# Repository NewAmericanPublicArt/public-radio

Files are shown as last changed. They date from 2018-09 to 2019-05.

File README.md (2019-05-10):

# Arduino Uno [Branch]
*NOTE* that this branch contains code for building the radio with an `Arduino Uno` using a slightly different board design. With this board we kept all of the components at 5V so we avoid all of the level-shifters that were required with the micro:bit. The board contains the following components:

 * Arduino Uno
 * [Adafruit Si4713]

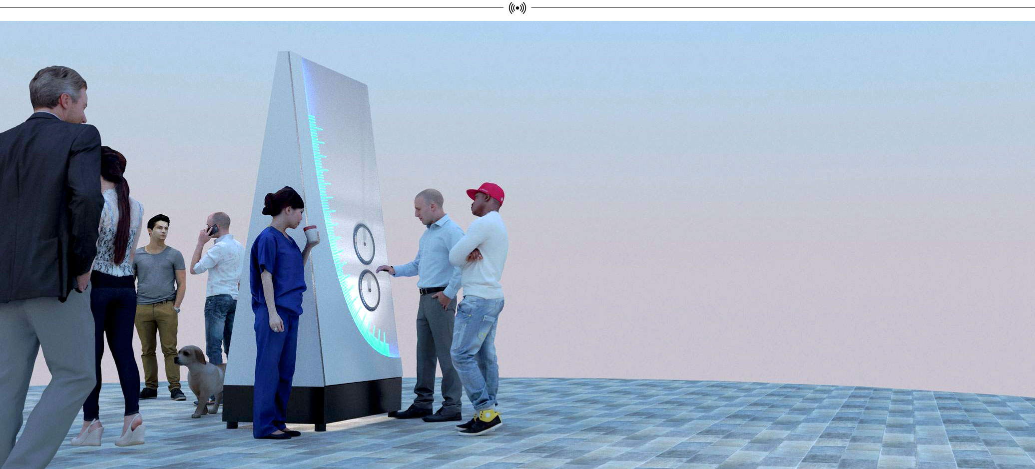
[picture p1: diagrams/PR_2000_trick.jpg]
title banner Public Radio Banner

# Public Radio
*Public Radio* was designed and fabricated by [New American Public Art](http://www.newamericanpublicart.com/) with electronic design &amp; programming by [Andrew Ringler](https://andrewringler.com/). This repository holds the Arduino code and electronic design documentation that drives the *Public Radio*.  

*Public Radio* is a large outdoor radio that continually plays over-the-air FM radio. It has two dials, one for changing station and one for changing volume. It provides visual feedback with LEDs of the currently selected station as well the current volume level. Additionally it provides audio feedback of the current station and volume by actually playing the selected FM station.

## New Developer Setup
The micro:bit was programmed using the Arduino IDE. If you need to make changes and re-upload the code first power off the radio, disconnect the USB cable from the micro:bit then pull the micro:bit out from the Dragontail connector.

In order to load the program onto a micro:bit you will need to:

 * Install the [Arduino IDE](https://www.arduino.cc/en/Main/Software) software
 * Follow the instructions at Adafruit's [Use Microbit with the Arduino IDE | Add NRF5x Board Support](https://learn.adafruit.com/use-micro-bit-with-arduino/install-board-and-blink#add-nrf5x-board-support-2-7) to add the NRF5x Board Support to your Arduino IDE. 
 * Download the entire repository: [as a zip here](https://github.com/NewAmericanPublicArt/public-radio/archive/master.zip)
 * From Arduino menu `Sketch > Include Library > Manage Libraries…` install the `Adafruit Dotstar` library (tested with v1.0.4) 

Once you have the NRF5x board installed, hook your micro:bit up to your computer via a USB cable. Then double-click the `PublicRadio/PublicRadio.ino` file to load the program in Arduino. Then update the following from Arduino menus `Tools > Board > BBC micro:bit`, `Tools > Softdevice > S110` and `Tools > Port > …BBC micro:bit…`

Then `Sketch > Upload`.

Put the micro:bit back into the Dragontail connector with the LED grid facing up. Power back on the radio.

## Design
*Public Radio* is a large 8x4 foot structure with an acrylic front panel. Two large dials (for channel tuning and volume changing) are mounted flush on the front panel. A curved string of LEDs are mounted on the interior left of the front panel which shine through to the outside providing visual feedback of the currently selected station. Tick marks and station labels (created by CNC cutting the front panel interior) line up with the LEDs. On the front bottom right a small string of LEDs provide visual feedback for the current volume level. Electronics (in waterproof boxes) as well as waterproof speakers are contained within the radio interior. The entire radio is controlled by a single BBC micro:bit.

A Fusion 360 model of the radio structure and components can be downloaded [here](https://a360.co/2QIU2CJ).

### Dials
The dials are attached to axles on the radio interior and on each axle is mounted a single black plexiglass disc with slits laser cut into an outer and an inner ring. The inner ring of slits is 1/2 slit-width out of phase with the outer ring. Two [Vernier VPG-BTD](https://www.vernier.com/products/sensors/vpg-btd/) photogates are mounted per encoder wheel such that one photogate measures the the outer ring of slits and the other photogate measures the inner ring of slits. This combination of using two photogates to measure the inner and outer rings of phase-shifted slits creates an optical incremental directional encoder whose readings we can interpret as a 2-bit Gray code pattern thus resolving the current speed of the axle and the direction the axle is rotating (clockwise versus counterclockwise). For more information on the concept of rotary encoders see [Rotary encoder](https://en.wikipedia.org/wiki/Rotary_encoder) on Wikipedia as well as Jeff Cook's University of Michigan [EECS 461](http://web.eecs.umich.edu/~jfr/embeddedctrls/lectures.html) Embedded Control Systems [Position and Velocity Lecture Notes](http://web.eecs.umich.edu/~jfr/embeddedctrls/files/Lecture3.pdf) (the lecture notes PDF is also available in our resources directory).

Each of the [Vernier VPG-BTD](https://www.vernier.com/products/sensors/vpg-btd/) Photogates is connected to a [Vernier BTA-ELV Analog Protoboard Adapter](https://www.vernier.com/products/accessories/protoboard-adapters/bta-elv/) which is a small breadboard compatible breakout board. We power the board with `5V` then measure pin `DIO0` which is `HIGH` when the photogate is blocked otherwise `LOW`. Since this is a `5V` board we first level-shift the `DIO0` signal down to `3.3V` with a `74AHCT125` level shifter then measure with a GPIO pin on the micro:bit.

We measure the speed and direction of each of the dials. If the station dial is turning clockwise the station increases, if the dial is turning counterclockwise the station decreases. The dials have no hard stops, so upon reaching the maximum station `107.9` while turning clockwise, we restart at the minimum station `86.5`, then continue to increase stations.

The volume dial also has no hard stops, but unlike the station dial, volume does not wrap-around from maximum volume to minimum volume since this would have created a jarring acoustic experience. Instead, we use a different technique we are calling `avocado volume`. Typically, while turning the volume dial clockwise the volume will increase until it reaches the maximum volume, then it will start decreasing, until it reaches the minimum volume, then it will start increasing again. So, if you continuously spin the dial clockwise, the volume of the radio will smoothly ramp up and down forever. Spinning the dials counterclockwise has the same behavior.

### Radio
The actual FM radio is driven by a digital `Si4703` FM tuner board. The micro:bit, on power-on, initializes the FM tuner board to a default station and volume. As the user changes station and volume, using the dials, these internal variables are updated and any changes are sent via `I²C` to the tuner board. The board tunes to the correct FM station and has a small pre-amp and 3.5mm audio jack. We hook a standard stereo audio cable to the board and then connect that to a standard audio amplifier which drives a set of waterproof consumer “deck” speakers.

The `Si4703` board we purchased (and most `Si4703` boards) did not have a separate FM antenna jack, instead the board pulls the signal from the shield of the audio cable. This is a less-than-ideal situation for FM reception. Madis Kaal [lists various options](http://www.nomad.ee/micros/silicon_radio/index.shtml) for dealing with this (also saved to the resources directory as *Si4703_MadisKaal_Antenna.pdf*). I decided to create a “breakout cable” that separates audio from the antenna.

#### Antenna | Audio Breakout Cable
The breakout cable is a stereo 3.5mm audio jack on one end (which attaches to the FM board) and the other end splits into a 3.5mm audio jack and a F-type RF connector (coax). The 3.5mm jack on the Si4703 board connects to a 3-part audio cable the 3 parts being [Tip, Ring and Shield/Sleeve aka TRS](https://en.wikipedia.org/wiki/Phone_connector_(audio)) which correspond to audio left, audio right and [antenna feed line](https://en.wikipedia.org/wiki/Feed_line). In the breakout cable the feedline is connected to the center conductor of the [F connector](https://en.wikipedia.org/wiki/F_connector) and the shield of the F connector is connected to a new ground line running to the board. On the audio side of the breakout cable the tip and ring are connected to the tip and ring again (IE left audio and right audio are as expected) and a new ground line is run to the shield of the audio cable (thus disconnecting the antenna feed line from the audio cable).

I connected the F connector to a standard dipole FM antenna via 75Ω coaxial cable. The audio cable is connected to a standard stereo audio amplifier and outdoor waterproof speakers.

### LEDs
384 `APA-102` LEDs curve along the left side of the front panel providing visual feedback of the current station. A small strip of 37 LEDs is on the bottom right side of the front panel providing feedback of current volume level. For wiring simplicity, all the LEDs are actually wired as a single continuously addressed strip of 421 LEDs with a small 6-inch jumper in between the station and volume LEDs so that to the volume LEDs could be physically and visually separated.

We chose APA-102 LEDs (over say WS2812B aka Adafruit Neopixels) since the APA-102s are a 4-wire spec with a dedicated clock line. Which essentially means they have very loose timing requirements because if you are interrupted by for example an interrupt you can just continue on after the interrupt with the correct clock signal. We actually read the photogates using interrupts so we don't miss any readings and can have very responsive dials. This would not have been possible with WS2812Bs. 

Again, like the Vernier photogates, the APA-102s are a 5V component so we used the 74AHCT125 level shifter to shift our 3.3V output from the micro:bit to the 5V level the APA-102s want. Although many 5V LEDs will sort-of tolerate a 3.3V input it is more robust to supply them with the 5V signal they expect.

### Breadboard Diagram:
Microbit controlling FM Receiver and APA102 LED light string:
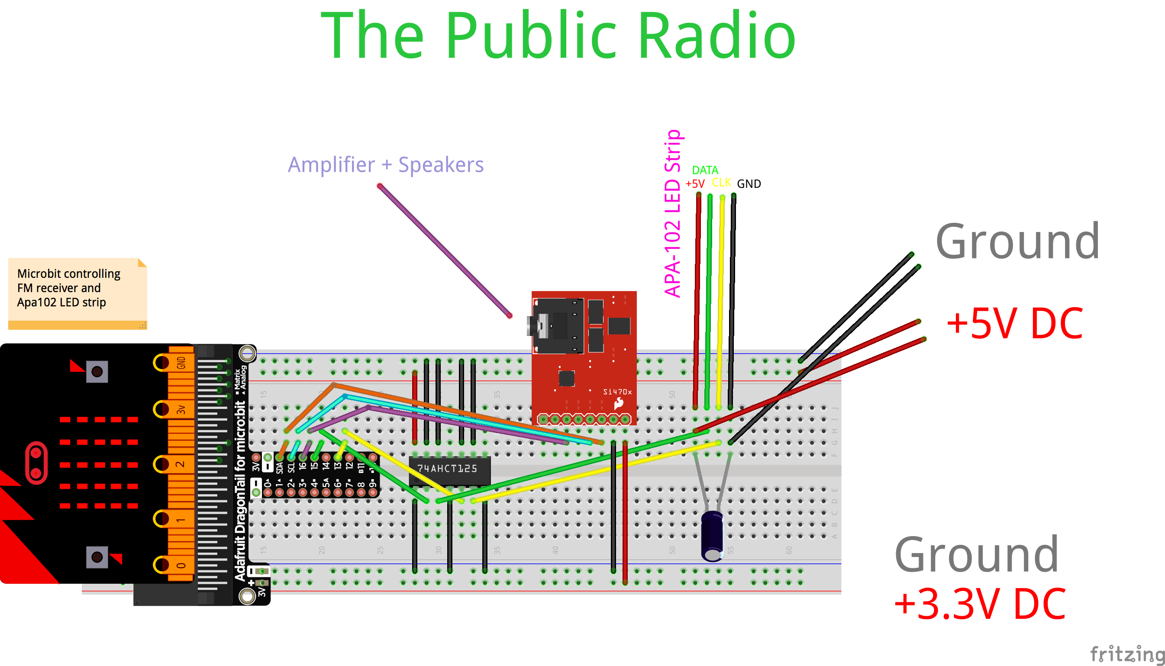
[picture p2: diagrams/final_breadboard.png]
breadboard diagram Breadboard Diagram


#### Electronics Parts List:
 * 3.3V BBC micro:bit
 * 5V APA102 LED Strip (aka Adafruit Dotstar)
 * 2x 1000 µF, 6.3V Capacitor
 * 3V Si4703 FM Digital Tuner Board
 * 4x 5V Vernier VPG-BTD Photogates
 * 4x 5V Vernier BTA-ELV Analog Protoboard Adapter
 * 2x 74AHCT125 Level Shifter 3V <-> 5V
 * Adafruit DragonTail for micro:bit

The capacitors are attached near the APA-102 strip where it is being powered so that [“the initial onrush of current won't damage the pixels”](https://learn.adafruit.com/adafruit-neopixel-uberguide/powering-neopixels).

<hr>

<br />This work is licensed under a <a rel="license" href="http://creativecommons.org/licenses/by-sa/4.0/">Creative Commons Attribution-ShareAlike 4.0 International License</a> except where otherwise noted.

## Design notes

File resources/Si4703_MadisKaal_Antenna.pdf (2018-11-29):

This is a followup on the using DL2416 (http://www.nomad.ee/micros/dl2416/) example. With addition of cheap FM tuner breakout module, rotary encoder, and optionally an analog VU meter for extra fancyness you can build guts of FM stereo radio that can also decode station names from RDS.

Lets get started (click on schematics to open full size version in new window).

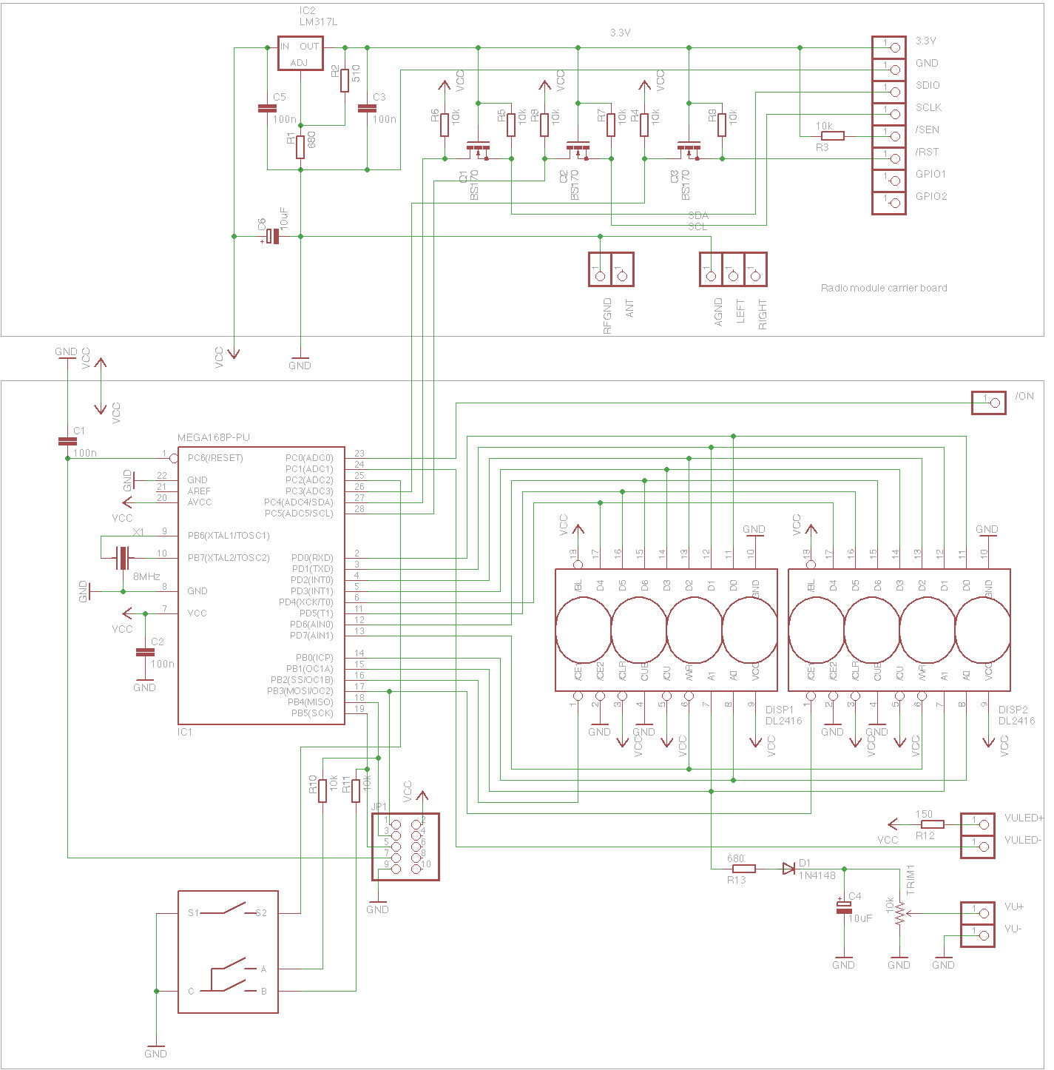
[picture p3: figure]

The circuit has two major logical section radio module part, and the control part. You can build them on a same board, or to separate boards. I want two separate boards for a receiver project, so that the radio is close to antenna connector while the control board is located at the front panel.
Radio module carrier board
Electronics (http://www.nomad.ee/micros/index.shtml) | Btrieve (http://www.nomad.ee/btrieve/index.shtml) | Motorcycling (http://www.nomad.ee/bike/index.shtml) | Software (http://www.nomad.ee/soft/index.shtml)

Radio receiver with RDS decoding using Si4703 breakout module

This board has a voltage regulator for 3.3V supply for radio module, and 3 level shifters for signals coming from control board. The Si4703 breakout boards are all clones of SparkFun FM Tuner Evaluation Board Si4703, and it has "VCC is 3.3V only!" notice on the schematics. My (https://www.sparkfun.com/products/12938) modules, labeled "CJMCU-470" use 5V capable TPA6111A2 chip for headphone amp and the Si4703 itself is also 5V tolerant, so these boards do not seem to have anything on them that would limit the VCC to 3.3V. Nevertheless, I added level shifters and voltage regulator in case anyone wants to use the original SparkFun boards, in case these really are 3.3V only.
Modifying the Si4703 breakout board for external antenna

The breakout board is built to use headphone cable shielding as an antenna. This is obviously no good if you want to build the module into receiver that has a proper antenna, for example this one. (http://www.nomad.ee/micros/fmantenna.shtml) Fortunately the mod is easy you just need to connect the antenna to headphone jack's ground connector, and antenna cable shield to breakout board's ground plane. I removed the headphone jack and used the holes for antenna and audio output wires, but you can just solder on the new wires with headphone jack in place. Thats how my module looked for plugging into solderless breadboard:

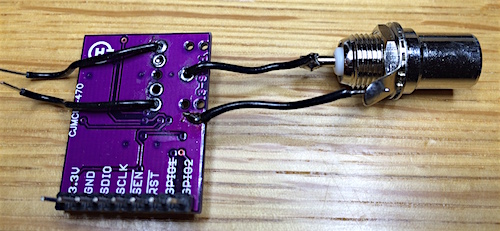
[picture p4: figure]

Control board

The control board is build around Atmega168, with two DL2416 bubble display modules attached to it (just like here). (http://www.nomad.ee/micros/dl2416/) I2C interface goes to radio board, along with one additional signal for configuring the Si4703 properly.

PC0 serves as ON/OFF input, pulling this input to ground 'turns on' the radio. The control board is obviously on all the time, but high level on PC0 input causes the display being blanked, VU meter and its backlight turned off, and radio also put into disabled state. In the off state the power consumption drops to about 10mA, while in the on state can reach 180mA or so, depending on what is shown on the display. Note that enabling the radio produces fairly heavy 'pop' on audio output.

PC1 is used to control VU meter backlight, it goes low when radio is 'on'.

Rotary encoder, such as Alps STEC11B01 (http://amzn.to/2cwx1my) is used for tuning, and pressing on the shaftconnected button saves the currently tuned frequency as default.

JP1 is ISP connector, in all my projects I've been using this nonstandard layout 10 pin connector that also allows taking 5V supply from USB port. It's great for building small projects on solderless breadboard. The encoder shares the pins with ISP connector, that is why I added R10,R11 there.
Optional VU meter

VU meter can be added to show radio signal level. The code reads RSSI value from the radio periodically and uses OC1A output to output PWM signal that is proportional to RSSI. If you do not want to use VU meter, then you do not need R13,D1,C4,TRIM1. These form a filter and rectifier to turn the PWM signal into analog voltage. If you plan to modify the code, then it is important to keep in mind that the OC1A output is also used as address A1 signal to displays. You have to stop the PWM generation before writing anything to display.
VU meter backlight modification

I wanted to use one of those small chinese VU meters. (http://amzn.to/2di1oy4) These swing full scale at about 0.5mA, so you do not need the control board that most sellers want to bundle for most cases. The backlight in these things is a small 12V bulb, and it is useless at 5V. Fortunately the meter is easy to modify. Just pry off the front, carefully because the scale may get stuck to front and needle is in front of the scale. You'll see the bulb in a back of a unit, replace it with led of whatever color you like, but before installing the led rough up its surface with sandpaper to diffuse the light better. I used orange led with flat top when prototyping. Yellow is probably a better choice, but I did not have any at hand.
Software

All C++ code is available at GitHub, in my silicon_radio (https://github.com/mastmees/silicon_radio) repository. I also made hex files available if you do not want to build the code yourself. For building you need a working make, avrg++, and avrdude. I have only build on OSX, feel free to contribute with build instructions for other platforms
Building

Just type make, and you should get hex and eep files. make flash will try to write the code to microcontroller using avrdude with usbtiny compatible programmer. make clean will clean the clutter from (http://amzn.to/2cUj2W0)

directory, and make erase will try to erase microcontroller's flash memory.
Code contents

Code should be quite understandable from comments. There are utility classes for display output, rotary encoder input, and PWM output for driving the VU meter.

Display is implemented so that it can show max 64 characters long text by scrolling it. This is the maximum length of text that radio text over RDS allows. Radio text is not shown as characters arrive, instead entire text block is collected, then stored in rds decoder to be used (and scrolled) when display changes to appropriate state.

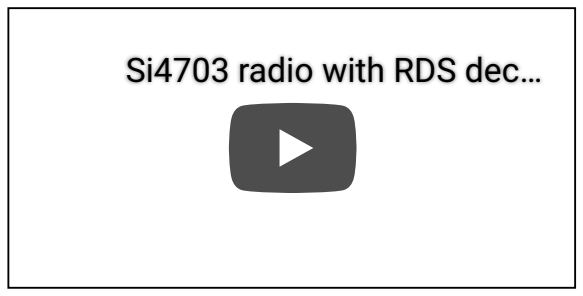
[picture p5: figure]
Si4703 radio with RDS dec…

The Si4703 control is implemented in 4 different files. Baseradio class defines interface that SI4703 class implements for specific chip. BaseRadio also has basic I2C reading and writing functions, and defines a generic RDS decoder. RDS decoder itself is implemented in separate file, the current implementation can decode basic info, station name, and radio text in its two different variations.

The main function after initialization runs in a loop where it goes to sleep, wakes up on any interrupt and sees what needs to be done in its current state. When radio is on, then the main loop calls radio.run() once every 4 timer ticks, and updates VU meter. radio_display() function is called on every interrupt to handle input and update display.

radio_display() has an array of functions that it calls in roundrobin fashion. Each function may display something, and with it return value tells the caller what it did. The result may be that a next function is tried, the display is kept static for a while, or the display is scrolled to show longer text.

Enjoy.

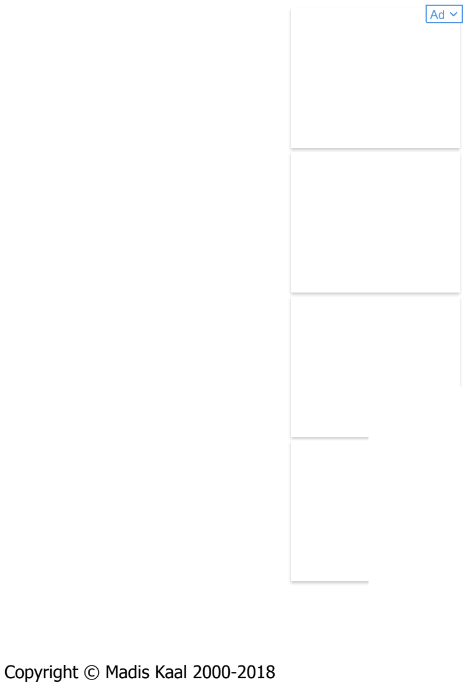
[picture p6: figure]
Copyright © Madis Kaal 2000-2018

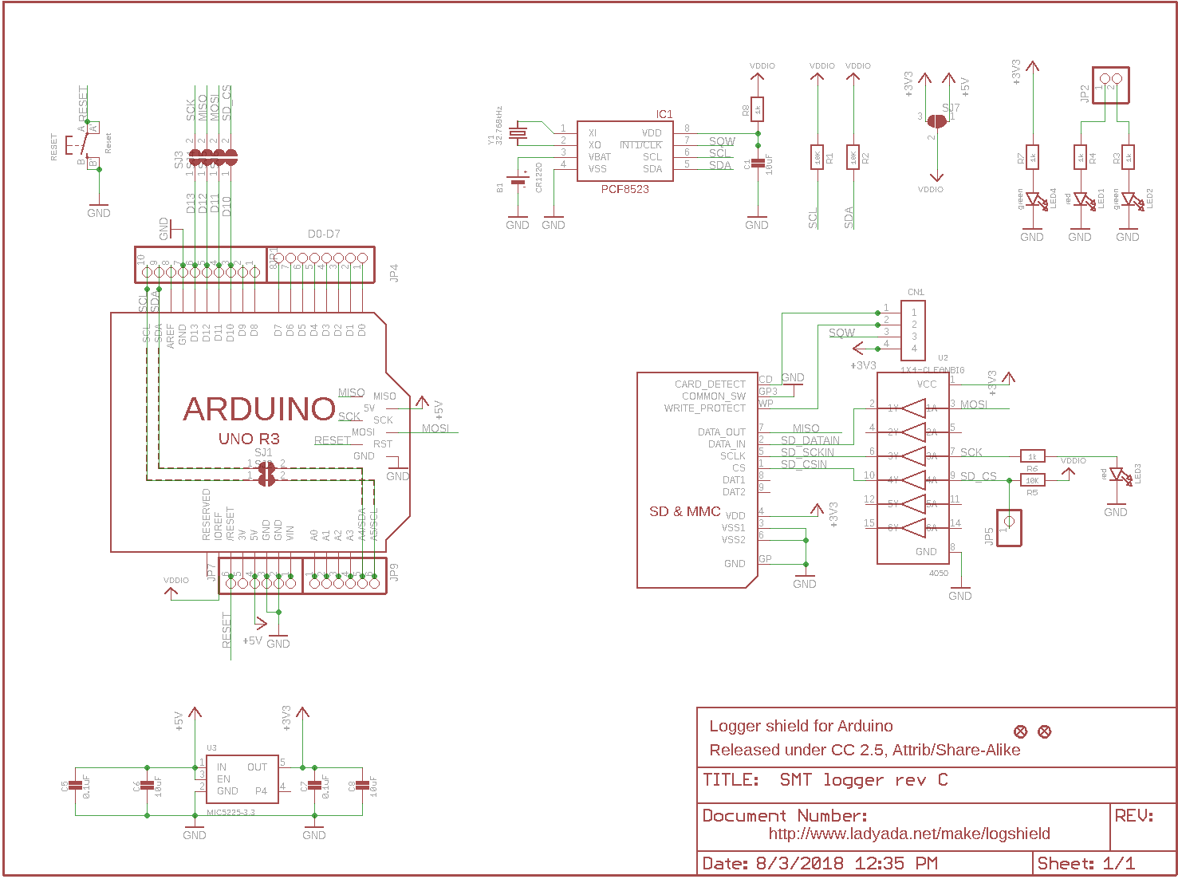
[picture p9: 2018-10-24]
resources/adafruit_products_schem.png

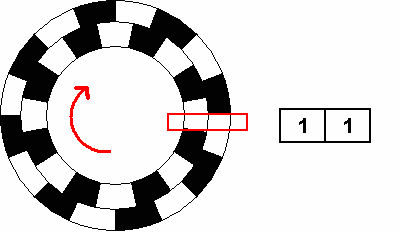
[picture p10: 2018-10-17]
resources/Incremental_directional_encoder.gif

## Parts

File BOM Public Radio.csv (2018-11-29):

Materials | Manufacture | Distributor | Cost | Quanity | Total Cost | Notes | Link
Electronics
Evaluation Board for Si4703 FM Tuner | sparkfun |  | 19.95 | 1 | 19.95 |  | https://www.amazon.com/Evaluation-Board-Si4703-FM-Tuner/dp/B00BLDKK64
Micro:Bit |  |  | 0 | 0 | 0 |  | https://www.amazon.com/BBC-BBC2546862-micro-bit-go/dp/B01G8X7VM2
Photo gate | Vernier |  | 0 | 2 | 0
Photo gate plug board | Vernier |  | 60 | 1 | 60
Dotstar LEDs | adafruit |  | 50 | 3 | 150 |  | https://www.adafruit.com/product/2242
PowerSupply 5V 20A |  |  | 35.49 | 1 | 35.49 |  | https://www.jameco.com/webapp/wcs/stores/servlet/ProductDisplay?catalogId=10001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
Si4703 FM Radio |  |  | $4.27 | 1 | $4.27 |  | https://www.banggood.com/CJMCU-470-Si4703-FM-Radio-Tuner-Evaluation-Development-Board-For-Arduino-p-1103101.html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
TEA5767 FM Radio |  |  | $8.16 | 1 | $8.16 |  | https://www.banggood.com/TEA5767-FM-Stereo-Radio-Module-76-108MHZ-For-Arduino-With-Antenna-p-1103142.html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
8GB Panasonic SD PCR242-ND |  |  | $32.34 | 1 | $32.34 |  | https://www.digikey.com/product-detail/en/panasonic-electronic-components/RP-SDPC08DA1/PCR242-ND/4318459
Adafruit Datalogging Shield + Stacking headers |  |  | $20.45 | 1 | $20.45 |  | https://www.adafruit.com/product/1141
Board Parts |  |  | 25.54 | 1 | 25.54
Wire |  |  | $13.03 | 1 | $13.03
Antenna Parts |  |  | $31.00 | 1 | $31.00
Speakers | Polk |  | 99 | 1 | 99 |  | https://www.amazon.com/gp/product/B00378KMEG/ref=oh_aui_search_detailpage?ie=UTF8&psc=1
Radio Transmitters |  |  | 30 | 1 | 30 |  | https://www.amazon.com/gp/product/B07C23V659/ref=ox_sc_act_title_1?smid=A320E5BUAF25R6&psc=1
Long audio cable |  |  | 3 | 1 | 3
Electrical Silicone |  |  | 13.1 | 1 | 13.1
LED volume cable management |  |  | 9 | 1 | 9 |  | https://www.amazon.com/gp/product/B06XGWXF5D/ref=ox_sc_act_title_1?smid=A2KZ7X05DCDJDL&psc=1
Cable management |  |  | 44.1 | 1 | 44.1 |  | mc master order 1031NART
 |  |  |  |  | 0
Shell
1/2" Acrylic |  | J Freeman | $313 | 1 | $313 |  | http://www.eplastics.com/ACRYCLR0-500PM48X96
3mm WHITE OmegaBond |  | J Freeman | $52 | 3 | $156 |  | http://www.tri-dee.com/Dibond%20Aluminium%20Composite%20Panels.htm
3mm Brushed Bronze OmegaBond |  | J Freeman | $94 | 1 | $94
Frame
1.5"x1.5" 16g sq tube x 24' |  | Turner Steel | 45.05 | 5 | 225.25 |  | https://www.metalsdepot.com/steel-products/steel-square-tube
Sq Tube feet inserts - 1/2 13 thread |  |  | 8.31 | 4 | 33.24 |  | https://www.mcmaster.com/#60945k22/=1djhbw2
Adjustable feet |  |  | $15 | 0 | $0 |  | https://www.mcmaster.com/6111k321
Srews long |  |  | $12 | 1 | $12 | pack of 25 | https://www.mcmaster.com/95829a270
washers |  |  | 5.88 | 1 | 5.88 | pack of 100 | https://www.mcmaster.com/90333a011
Screw Short |  |  | 10.49 | 2 | 20.98 | pack of 25 | https://www.mcmaster.com/95829a260
 |  |  |  |  | 0
Dials
BearingRing |  |  | $37 | 2 | $74 |  | https://www.mcmaster.com/#18635a52/=1diy1k2
Missalignment coupling |  |  | $30 | 2 | $60 |  | https://www.mcmaster.com/#6183k61/=1dinypp
FaceMount shaft collar |  |  | 16 | 4 | 64 |  | https://www.mcmaster.com/#5631t11/=1diyepu
Pillow Block |  |  | 28 | 4 | 112 |  | https://www.mcmaster.com/#2031n14/=1diy9hc
Shaft |  |  | 11 | 2 | 22 |  | https://www.mcmaster.com/#5947k13/=1diydew
1" - 8-32 bolts |  |  | 9.88 | 1 | 9.88 | pack of 25 | https://www.mcmaster.com/98164a143
7/16" - 8-32 bolts |  |  | 5.77 | 1 | 5.77 | pack of 50 | https://www.mcmaster.com/98164a449
1" - 5-16 bolts for out ring |  |  | 7.39 | 1 | 7.39 | pack of 25 | https://www.mcmaster.com/92949a582
1" - 1/4-20 bolts for inner ring |  |  | 8.49 | 1 | 8.49 | pack of 50 | https://www.mcmaster.com/92949a542
Shaft Collars |  |  | 1.31 | 4 | 5.24 |  | https://www.mcmaster.com/6432k16
5/16" - Pillow block bolts |  |  | 7.5 | 1 | 7.5 | pack of 25 | https://www.mcmaster.com/91251a591
pillow block leveling washers |  |  | 11.5 | 1 | 11.5 | pack of 100 | https://www.mcmaster.com/91090a119
1/2" - 10-24 bolts - tamp res hex |  |  | 8.06 | 1 | 8.06 | pack of 25 | https://www.mcmaster.com/90517a312
1" - 10-24 bolts - tamp res hex |  |  | 3.61 | 2 | 7.22 | pack of 100 | https://www.mcmaster.com/90517a314
220 sand disk hook loop |  |  | 9.39 | 1 | 9.39 | pack of 25 | https://www.mcmaster.com/4724a148
DCM glue |  |  | 18 | 1 | 18 | 16oz | https://www.mcmaster.com/7517a4
squeex bottle |  |  | 9.5 | 1 | 9.5 | pack of 5 | https://www.mcmaster.com/7544a66
squeeze needle |  |  | 12.43 | 1 | 12.43 | pack of 50 | https://www.mcmaster.com/75165a687
 |  |  |  |  | 0
Total Material Costs
 |  |  |  |  | 1911.18

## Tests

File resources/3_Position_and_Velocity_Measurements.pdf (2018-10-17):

### Position and Velocity Measurements

- Important in many embedded applications, especially those in which the microprocessor must interface to mechanical hardware.
- Question: How many examples can you name?
- Many microcontrollers have special features that expedite such measurements.
- The MPC5643L has an enhanced motor control timer (eTimer) that performs counting and timing operations and can be used for input or output processing:
- Quadrature Decoding
- many others...
- Analog vs. Digital Measurement Technology
- Signal/Noise ratio (S/N)
- Dynamic Range (largest vs. smallest measurements)
- Information about technology for position and velocity measurements can be found in many textbooks, including [3], [4], and [6]. Reference [3] was used primarily in developing this set of notes.
EECS461, Lecture 3, updated September 8, 2015 | 1

### Analog Velocity Measurement

- Tachometer: produces a voltage proportional to velocity (usually rotational velocity)
- same operating principle as DC motor; in fact, it is possible to use a DC motor as a tachometer. (will describe when we discuss DC motors)
- tachometer performance is often limited by noise (e.g., brush noise)
- at low velocities S/N ratio is poor, and it is difficult to determine when velocity is zero (i.e., when the mechanical system is stopped)

### Analog Position Measurement

- Potentiometer: produces a voltage proportional to distance from a reference point
- Example: Measure distance of a cart from one end of a track
- Since there is a sliding mechanical contact, noise, dirt, humidity, and mechanical wear limit precision.
- The maximum range is also limited!

### Optical Encoder

- Often used for digital position and velocity measurement
- Two types
- absolute encoders: gives actual position
- incremental encoders: gives change in position
- Usually encoders measure angular displacement
- can be used to measure rectilinear position
- computer mouse (2-dimensional position!)
- Will first discuss incremental encoder, because we will use in lab.

### Incremental Encoder

- a wheel with little windows (front and side views):
LED | light sensor

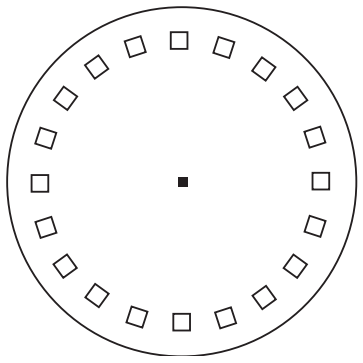
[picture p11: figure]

- As wheel rotates, the photocell generates a pulse train:

0

1

- If windows and dividers are of equal width, then the “on” and “off” times are of equal duration for constant rotation rate.

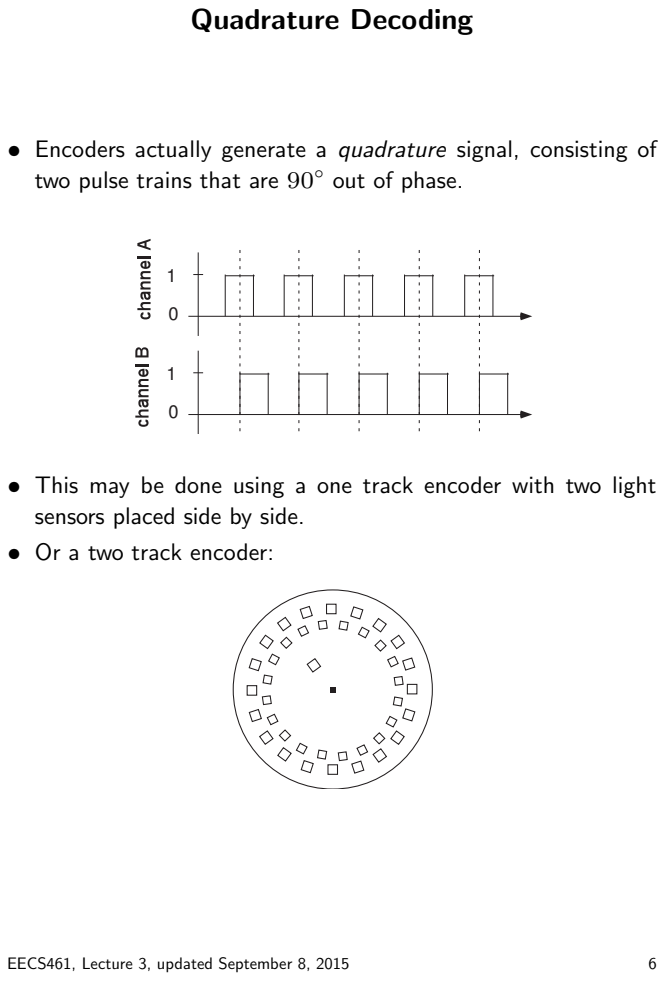
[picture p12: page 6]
Quadrature Decoding

• Encoders actually generate a quadrature signal, consisting of
two pulse trains that are 90◦

out of phase.

• This may be done using a one track encoder with two light
sensors placed side by side.
• Or a two track encoder:

### Direction of Rotation

- Direction of rotation is determined by the phase difference between the two signals
- For example, if Channel A leads Channel B, then the encoder is rotating (say) CCW

0

1

0

1

- If Channel B leads Channel A, then the direction of rotation is CW

0

1

0

1

- Most encoders have an extra track, with just one window, that may be used for alignment to determine absolute position at startup.

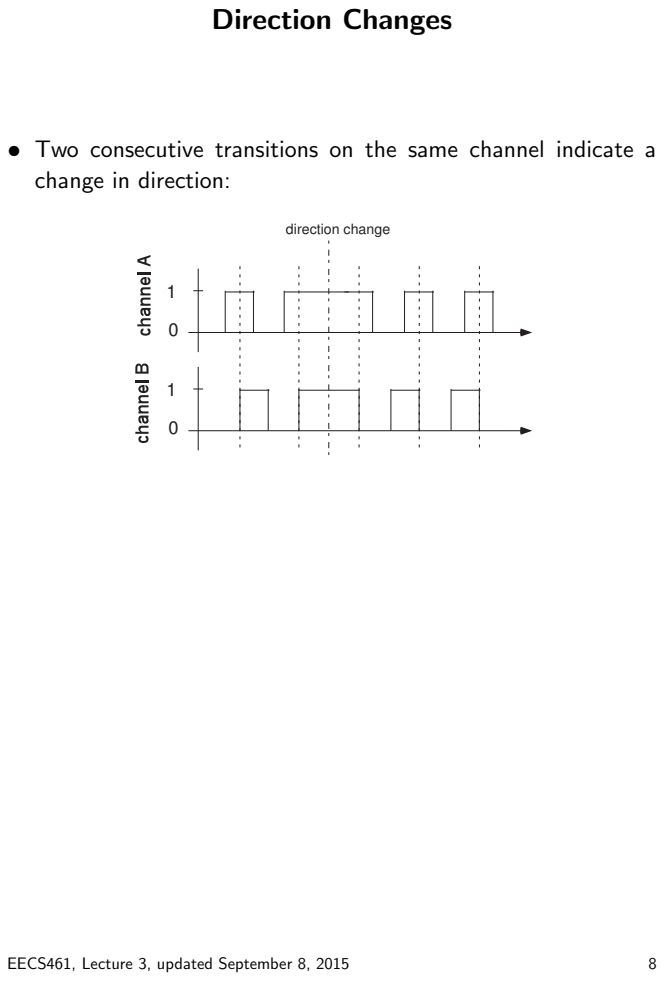
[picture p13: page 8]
Direction Changes; direction change

• Two consecutive transitions on the same channel indicate a
change in direction:

### Encoder Operation Modes

- The idea of quadrature decoding is to increment or decrement a counter based on transitions, or rising and falling edges, of the two pulse train signals. The counter is incremented if the phase difference between channels indicates CCW movement, and decremented otherwise.
- Several types of decoding
- 1X: the counter is incremented or decremented only according to rising edges of Channel A. (Lowest resolution)
- 2X: the counter is incremented or decremented according to both rising and falling edges of Channel A. (Higher resolution)
- 4X: the counter is incremented or decremented according to rising and falling edges of Channels A and B. (Highest resolution)
- The eTimer on the MPC5643L has several quadrature decoding modes:
- CNTMODE = 001: like 1X mode except direction not determined
- CNTMODE = 010: like 2X mode except direction not determined
- CNTMODE = 100: same as 4X mode including direction information

### Encoder Operating Modes: MPC5553

- Several types of decoding
- 1X: the counter is incremented or decremented only according to rising edges of Channel A. (Lowest resolution)
- 2X: the counter is incremented or decremented according to both rising and falling edges of Channel A. (Higher resolution)
- 4X: the counter is incremented or decremented according to rising and falling edges of Channels A and B. (Highest resolution)
- The QD eTPU function on the MPC5553 has three modes: slow, normal, and fast [5].
- slow: the same as 4X mode
- normal: the same as 4X mode except that direction is not determined
- fast: the same as 1X mode, except that direction is not determined

### Resolution of Encoder

Question: How to determine resolution in degrees of rotation/transition? Suppose there are N windows/track.

- 1X mode:
- There are N transitions per 1 complete revolution.
- Each transition corresponds to a displacement of 360◦/N.
- 2X mode:
- There are 2N transitions per 1 complete revolution.
- Each transition corresponds to a displacement of 360◦/2N.
- 4X mode:
- There are 4N transitions per 1 complete revolution.
- Each transition corresponds to a displacement of 360◦/4N.

TERMINOLOGY: Different manufacturers use different terminology to describe encoder resolution. When one see reference to a “500 pulse” encoder, one must read the documentation carefully to determine the total number of transitions, or rising and falling edges, on both channels.
- In the EECS 461 lab we use a 1000 cycle per revolution (CPR) encoder.
- For a definition of CPR, see the website [1].

### Issues

- If the encoder is moving too fast, then the sharp edges of the square wave may be so distorted that a transition escapes detection.
- a problem with the physical time constants
- Noise may cause spurious transitions
- ignore short duration pulses
- ignore pulses that result in invalid transitions
- a spurious pulse that occurs on only one channel may cancel itself out
- spurious pulses that occur on both channels can result in errors
- Must insure that when the CPU reads the counter, it does not obtain a spurious value due to reading it while it is being updated.

### Encoder Counter Register Overflow

- As haptic wheel turns, the encoder attached to the motor shaft turns at the same rate
- Quadrature decode routine updates an n-bit counter register that keeps tracks of wheel position
- n-bit register may be viewed as a wheel labelled from 000 to, e.g., 111 (n = 3) or FFFF (n = 16)

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
- If not read sufficiently often, the count register may overflow (i.e., count up to 111 then to 000) or underflow (count down to 000 then to 111)
- To avoid problems, use 2’s complement arithmetic to subtract previous from current readings to obtain position increment.
- However, counter register must be read before ambiguity can occur

### Two’s Complement Arithmetic, I

- A way to represent signed decimal numbers in n-bit binary form.
- Case 1: Nonnegative Number
(i). convert unsigned portion into (n − 1)-bit binary (ii). set leading bit to 0
- Case 2: Negative Number
(i). convert unsigned portion into (n − 1)-bit binary (ii). take 1’s complement (change all 0’s to 1, all 1’s to 0) (iii). add 1
(iv). set leading bit to 1
- Example: n = 8. Represent 6 in 2’s complement (i). 6 → 0000110
(ii). set leading bit to 0: 0000110 → 00000110
- Example: n = 8. Represent −6 in 2’s complement (i). 6 → 0000110
(ii). take 1’s complement 0000110 → 1111001 (iii). add 1: 1111001 + 0000001 = 1111010 (iv). set leading bit to 1: 1111010 → 11111010

### Two’s Complement Arithmetic, II

- 2

n−1
nonnegative, and 2

n−1
negative numbers
- Example: n = 3
decimal | binary
-4 | 100
-3 | 101
-2 | 110
-1 | 111
0 | 000
1 | 001
2 | 010
3 | 011
- Note that
- positive numbers always have “0” as the most significant bit
- negative numbers always have “1” as the most significant bit

### Sign Extension

- Sometimes it is necessary to convert an n-bit two’s complement number into a 2n-bit number
- It is necessary that the leading bit of the n-bit number be “extended” so the the 2n-bit number has the correct sign
- Example: n = 2 → n = 4
decimal | 2-bit | decimal | 4-bit
| | -8 | 1000
| | -7 | 1001
| | -6 | 1010
| | -5 | 1011
| | -4 | 1100
| | -3 | 1101
-2 | 10 | -2 | 1110
-1 | 11 | -1 | 1111
0 | 00 | 0 | 0000
1 | 01 | 1 | 0001
| | 2 | 0010
| | 3 | 0011
| | 4 | 0100
| | 5 | 0101
| | 6 | 0110
| | 7 | 0111
- Note: simply converting the 2-bit number to a 4-bit number by adding leading zeros will yield the wrong answer!

### Calculating Change in Wheel Position

- How to calculate position change?
- Example: 3-bit counter register (CCW = forward)

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
- Example 1
- Suppose previous reading is 101
- Current reading is 000
- Subtract: 000 − 101 = 011 ⇒ 3 forward steps
- Example 2
- Suppose previous reading is 101
- Current reading is 011
- Subtract: 011 − 101 = 110 ⇒ 2 backward steps
- Necessary to read counter often enough that directional information isn’t lost (at most 3 forward or 4 backward steps)
- Example 3
- Suppose previous reading is 101
- and current reading is 001
- Subtract: 001 − 101 = 100 ⇒ 4 backward steps
- Ambiguity: It could also be 4 forward steps....
⇒ Recall our discussion of aliasing and the rotating wheel!

### Velocity from a Position Encoder

- Using counter
- If counter is read (sampled) at regular intervals, then position increment is proportional to average velocity over the period between samples.
- Problem: Low velocity may read inaccurately or even zero.
- Using frequency of pulses
- Count frequency of pulses: the number of pulses per time interval
- Same problem at low velocity
- Using period of pulses
- Count period of pulses: the time between consecutive pulses
- Problem: at high velocity, too little time between pulses
- Problems of period counting and frequency counting are complementary

### Absolute Encoders

- Gives absolute (not relative!) position directly in digital form
- Uses several tracks: n tracks for an n-bit absolute encoder yields 2

n
sectors, with resolution (360/2

n
)

◦

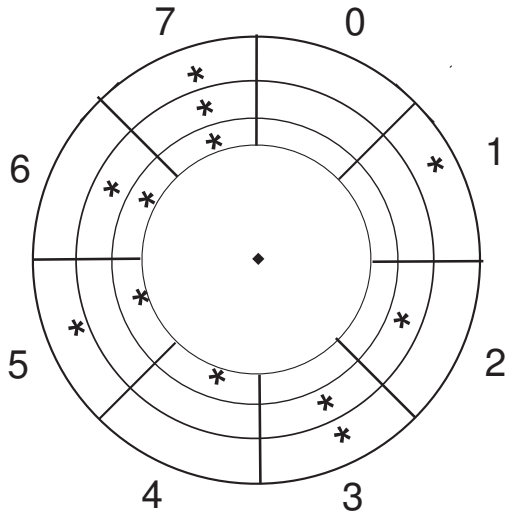
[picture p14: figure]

- Problem: multi-bit changes
- If position is recorded while in transition, then it may be wildly wrong: 3→ 4 yields 7 which is 180◦
incorrect!
- Since it is impossible to know when the wheel is going to move, can never guarantee that it won’t move while being read
- Sensors for each track must be carefully aligned, otherwise, some could be reading one sector, and others could be reading adjacent sector
- Solution: use Gray code [2] instead of natural binary

### Gray Code

- Idea: Represent consecutive decimal numbers using binary numbers that differ in only one digit
- Example: 3-bit Gray code
decimal | natural binary | Gray
0 | 000 | 000
1 | 001 | 001
2 | 010 | 011
3 | 011 | 010
4 | 100 | 110
5 | 101 | 111
6 | 110 | 101
7 | 111 | 100

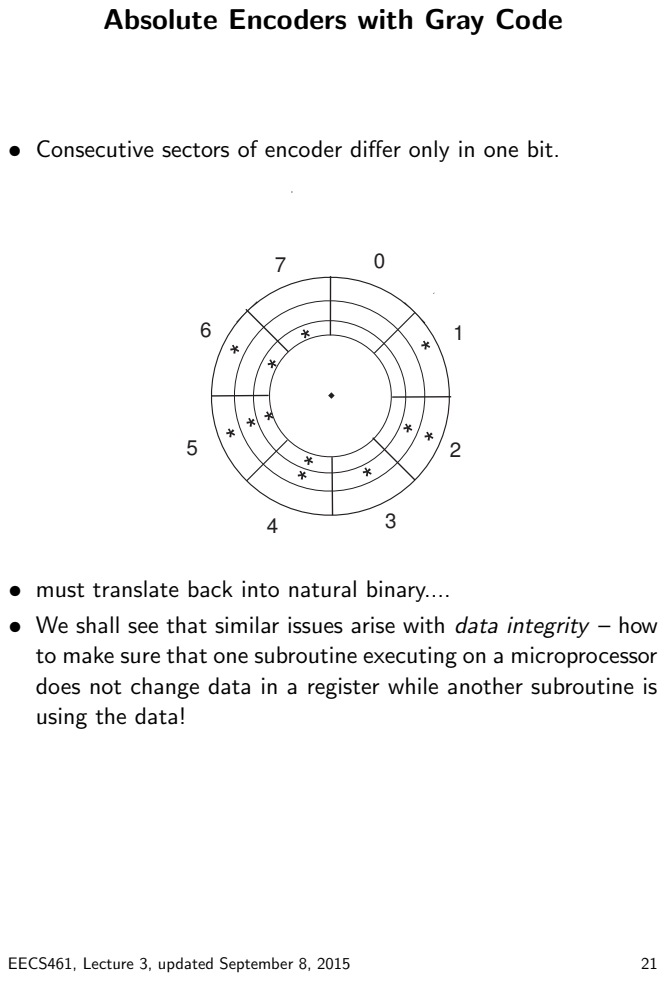
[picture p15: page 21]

Absolute Encoders with Gray Code

• Consecutive sectors of encoder differ only in one bit.

• must translate back into natural binary....
• We shall see that similar issues arise with data integrity – how
to make sure that one subroutine executing on a microprocessor
does not change data in a register while another subroutine is
using the data!

### References

[1] http://usdigital.com/support/glossary/.
[2] http://en.wikipedia.org/wiki/Gray code.
[3] D. Auslander and C. J. Kempf. Mechatronics: Mechanical Systems Interfacing. Prentice-Hall, 1996.
[4] W. Bolton. Mechatronics: Electronic Control Systems in Mechanical and Elecrical Engineering, 2nd ed. Longman, 1999.
[5] M. Brejl, M. Princ, and A. Butok. Using the Quadrature Decoder (QD) eT P U Function. Freescale Semiconductor, Application Note AN2842, April 2005.
[6] C. W. deSilva. Control Sensors and Actuators. Prentice Hall, 1989.

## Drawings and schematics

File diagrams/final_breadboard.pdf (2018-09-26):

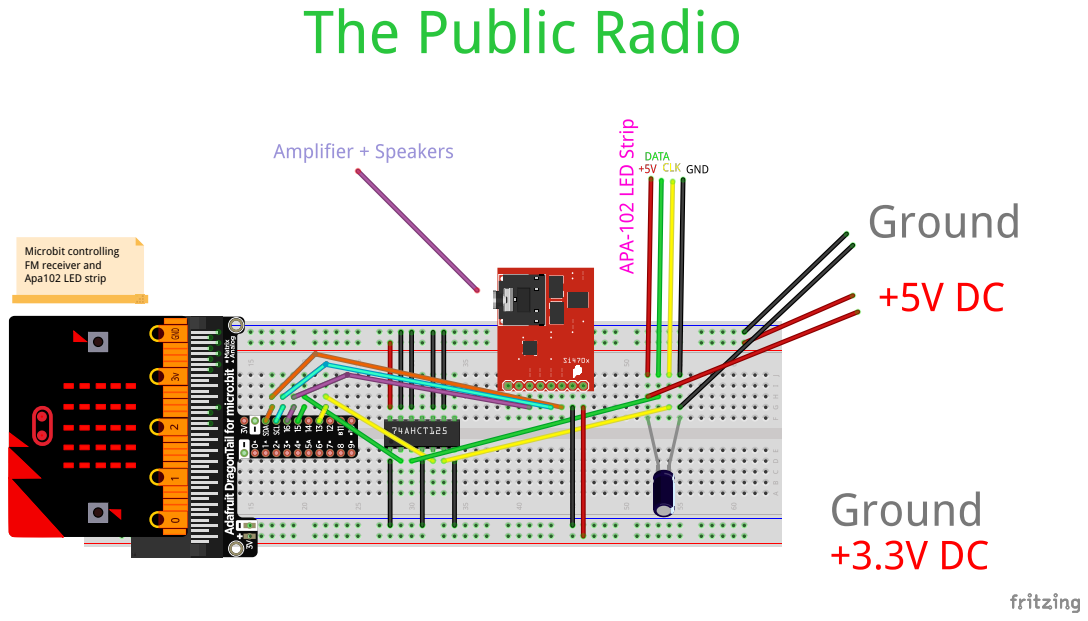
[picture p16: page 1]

Microbit controlling
FM receiver and
Apa102 LED strip

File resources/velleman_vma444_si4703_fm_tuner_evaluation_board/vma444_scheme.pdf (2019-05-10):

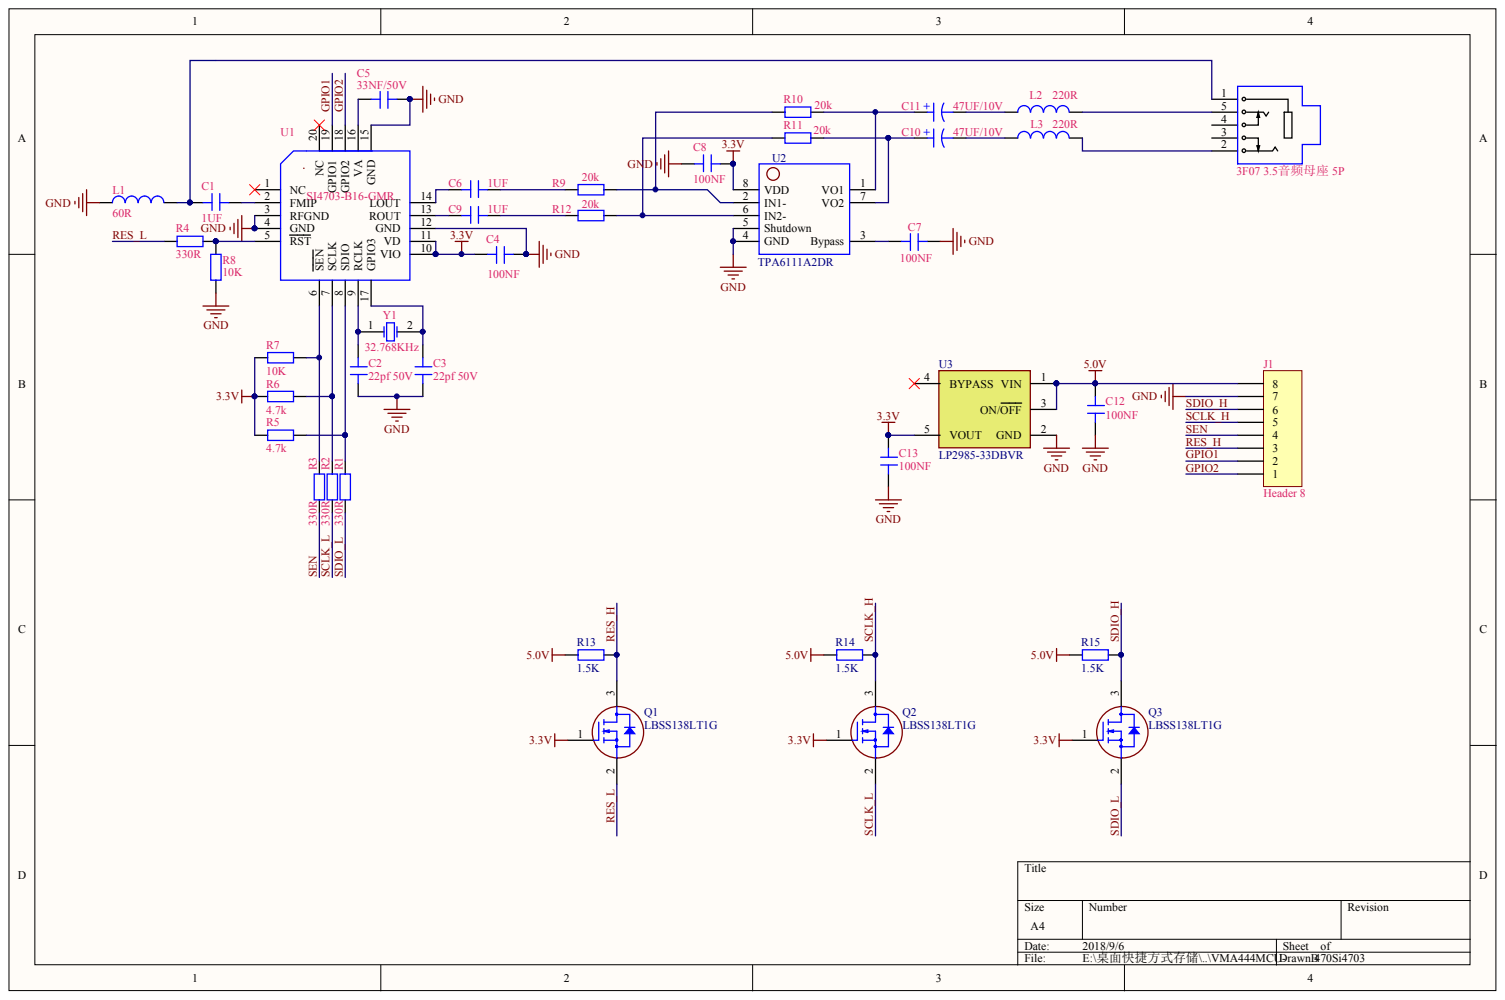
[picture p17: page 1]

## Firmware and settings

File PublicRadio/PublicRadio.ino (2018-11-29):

// Works with Microbit, LinkSprite Si4703 FM Radio, Line Level Convertor BSS138, Vernier Photogates
// See diagrams directory for a wiring guide
// This is meant to be built from the Arduino IDE then loaded onto a Microbit
//
// Microbit pinouts: https://microbit.org/guide/hardware/pins/
//
// Line Level Convertor BSS138
// https://www.adafruit.com/product/757
// Hook up low side to microbit
// Power high side off of 5V power supply
// Run high side line levels to FM board
// Power FM board off of 3V microbit
//
// LinkSprite Si4703 FM Radio Board:
// http://store.linksprite.com/breakout-board-for-si4703-fm-tuner/
// http://linksprite.com/wiki/index.php?title=Main_Page
// although the Si4703 chip is a 3.3V chip, the LinkSprite board needs to be
// powered at 3.3V, but expects 5V line levels for control
// *** Hmmm, actually it seems the board works at 3.3V?
//
// Getting Started:
// 1) Follow Microbit Arduino startup instructions: https://learn.adafruit.com/use-micro-bit-with-arduino/overview
//    Install Si4703_FMRadio library, https://github.com/whiteneon/Si4703_FMRadio
//    Install Adafruit GFX Library
//    Install BLE Peripheral Library
//    Install Adafruit_Microbit Library https://github.com/adafruit/Adafruit_Microbit/archive/master.zip
//
//
// 2) Wire up board pins: SDIO, SCLK, Reset, Ground, 3.3V
// 3) Upload code to Arduino
// 4) Turn on Serial Monitor, set to 57600
// 5) Change Volume or Station via Serial monitor
//    Change Stations via A and B buttons (A is seek down, B is seek up)
//
#include <Wire.h>
#include <SPI.h>

// PINS /////////////////////
const int PHOTOGATE1A_PIN = 0; //GPIO (general purpose digital input and output) with analogue to digital convertor (ADC)
const int PHOTOGATE1B_PIN = 1; //GPIO with ADC
const int PHOTOGATE2A_PIN = 2; //GPIO with ADC
const int PHOTOGATE2B_PIN = 8; //Dedicated GPIO, for sending and sensing digital signals.

const int buttonA = 5;     // the number of the pushbutton pin
const int buttonB = 11;     // the number of the pushbutton pin
const int RADIO_RESET_PIN = 16;
const int RADIO_SDIO = SDA; // P20 on Micro:bit
const int RADIO_SCLK = SCL; // P19 on Micro:bit

// CONSTANTS ////////////////
#define SERIAL_DEBUG false // serial control is not useful in production and has a performance hit, leave disabled
#define NUM_STATIONS 108 // we have a few extra ticks so we'll do 86.5—107.9 (108 Stations)
#define MINFREQ 865
#define MAXFREQ 1079
#define MAX_VOLUME 15 // Si-4703 API volume ranges from 0—15
#define MIN_VOLUME 0

#define LEDS_PER_STATION 3 // LED offsets will start at the leading edge of the plastic tick/finger
#define LED_FUDGE_FACTOR 2 // we don't have exactly 3 leds per station, since they get offset over time…
#define STATION_COLORS_LENGTH (NUM_STATIONS * LEDS_PER_STATION - LED_FUDGE_FACTOR)
#define NUMPIXELS 421 // Number of LEDs in strip (old 432)
#define VOLUME_NUM_PIXELS 37 // Number of LEDs for Volume Feedback
#define VOLUME_CENTER_PIXEL int(VOLUME_NUM_PIXELS/2)
#define STATION_PIXEL_START_INDEX VOLUME_NUM_PIXELS + 17
#define STATION_PIXEL_END_INDEX (STATION_PIXEL_START_INDEX + STATION_COLORS_LENGTH - 1)

// VARIABLES ////////////////
int volume = 5; // default volume on power-on
int channel = MINFREQ; // default channel on power-on
unsigned long lastStationDialChangeChangeMicros = 0;

void setup() {
#if defined(__AVR_ATtiny85__) && (F_CPU == 16000000L)
  clock_prescale_set(clock_div_1); // Enable 16 MHz on Trinket
#endif

  ledsSetup();
#ifdef SERIAL_DEBUG
  serialControlSetup();
#endif

  pinMode(buttonA, INPUT);
  pinMode(buttonB, INPUT);

  pinMode(PHOTOGATE1A_PIN, INPUT); // channel tuning photogate
  pinMode(PHOTOGATE1B_PIN, INPUT); // channel tuning photogate
  pinMode(PHOTOGATE2A_PIN, INPUT); // volume control photogate
  pinMode(PHOTOGATE2B_PIN, INPUT); // volume control photogate

  radioSetup();

  // Read photogates on input change
  attachInterrupt(digitalPinToInterrupt(PHOTOGATE1A_PIN), readPhotogate1, CHANGE);
  attachInterrupt(digitalPinToInterrupt(PHOTOGATE1B_PIN), readPhotogate1, CHANGE);
  attachInterrupt(digitalPinToInterrupt(PHOTOGATE2A_PIN), readPhotogate2, CHANGE);
  attachInterrupt(digitalPinToInterrupt(PHOTOGATE2B_PIN), readPhotogate2, CHANGE);
}

void loop() {
  // channelTuningWithMicrobitButtons(); // add-in for debugging
  updateRadio();
  updatePixels();
#ifdef SERIAL_DEBUG
  serialControlInLoop(); // serial control is not useful in production and has a performance hit, leave disabled
#endif
}

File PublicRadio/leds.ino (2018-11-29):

#include <Adafruit_DotStar.h>

// see https://github.com/adafruit/Adafruit_DotStar/blob/master/Adafruit_DotStar.cpp
#define PIC32 // force slower clock speed for voltage level converter SN54AHCT125

// Use Microbit's SPI, Apa102 Data -> Microbit MOSI AKA pin 15, Apa102 Clock -> Microbit SCK AKA pin 13
Adafruit_DotStar strip = Adafruit_DotStar(NUMPIXELS, DOTSTAR_BGR);


// Setup colors RGB 0-255
uint32_t offbandColor = strip.Color(3, 41, 38);
uint32_t volumeOnColor = strip.Color(20, 20, 255);
uint32_t volumeOffColor = strip.Color(0, 0, 0);
uint32_t white = strip.Color(255, 255, 255); // current station color
uint32_t gradientColor1 = strip.Color(255, 0, 0); // gradient near current station
uint32_t gradientColor2 = strip.Color(0, 0, 255); // gradient color 1/2 way away from station

/* Current station is index-0 */
uint32_t stationColors[STATION_COLORS_LENGTH];

// The moving waves coming of current station
struct LightPulse {
  int location;  // index within just the station LEDs
  unsigned long timeOfLastChange;
  unsigned long birth;
  int direction; // positive: increase station, negative: decrease station
  boolean alive;
};

// if we ever exceed MAX_LIGHT_PULSES we'll just delete the oldest pulse
#define MAX_LIGHT_PULSES 20
LightPulse lightPulses[MAX_LIGHT_PULSES];
int lightPulseIndex = 0;
boolean sendNewPulse = false;
unsigned long lastPulseCreate = 0;
int PULSE_SPEED = 1; // larger is faster
unsigned long DELAY_BETWEEN_PULSE_UPDATES = 50; // micros to wait on each LED before transitioning to the next
unsigned long MIN_WAIT_UNTIL_PULSE_START = 500000; // micros to wait until a pulse first starts after station stops
unsigned long PULSE_MAX_LIFE = 2000000; // max micros a pulse exists before it is deleted
// pulse generation is coupled to breathing animation

int PULSE_WIDTH_HALF = 6; // pulse width is twice this width + 1 (the center)
// we don't want to send pulses to the edge if we are really close to the edge
// because they won't look good
#define MIN_DISTANCE_FROM_EDGE_FOR_PULSE_START 20
/* a tick is 4-bulbs wide but is indexed off the leading edge of the tick
   so our pulse starts 2 indices below the tick and 3 indices above */
#define PULSE_START_OFFSET_LOW 2
#define PULSE_START_OFFSET_HIGH 3
// index into Dotstar library sine table at which we will send a new pulse
// we want this less then 255 value so it appears the pulse is sent as we approach 255
#define SINE_TABLE_255_SEND_PULSE 8
#define SINE_TABLE_255 62 // index of a 255 value in Dotstar library sine table
uint8_t centerPulseSineTime255 = SINE_TABLE_255;
unsigned long CENTER_TICK_SPEED = 300; // breathing speed (smaller is faster)
unsigned long centerTickLastTimeChange = 0;

unsigned long MIN_DELAY_BETWEEN_LED_UPDATES = 16000; // ~60fps, IE 1000ms/60 ~= 16 * 1000
unsigned long lastLEDUpdate = 0;

void ledsSetup() {
  // Clear light pulse array
  for (int i = 0; i < MAX_LIGHT_PULSES; i++) {
    lightPulses[i].location = 0;
    lightPulses[i].timeOfLastChange = 0;
    lightPulses[i].birth = 0;
    lightPulses[i].direction = 0;
    lightPulses[i].alive = false;
  }

  /* Sliding array of colors, used to animate current station
      pixels last,0,1,2 is always the tick representing the current station
      depending on the current station we will “slide” this array into position
      we'll surround the current station with off pixels so it stands out
  */
  // clear array
  for (int i = 0; i < STATION_COLORS_LENGTH; i++) {
    stationColors[i] = strip.Color(0, 0, 0);
  }

  // Setup sliding animation array (gradient that shifts as we change station)
  // setup colors around current station
  stationColors[0] = white;
  stationColors[1] = white;
  stationColors[2] = white;
  stationColors[3] = gradientColor1;
  stationColors[4] = gradientColor1;
  stationColors[5] = gradientColor1;

  // setup colors around current station (wrap)
  stationColors[STATION_COLORS_LENGTH - 4] = gradientColor1;
  stationColors[STATION_COLORS_LENGTH - 3] = gradientColor1;
  stationColors[STATION_COLORS_LENGTH - 2] = gradientColor1;
  stationColors[STATION_COLORS_LENGTH - 1] = white;

  // Setup actual gradient of colors (IE the colors that aren't the current station)
  for (int i = 6; i <= (STATION_COLORS_LENGTH - 5); i++) {
    if (i <= STATION_COLORS_LENGTH / 2) {
      // gradient from gradientColor1 to gradientColor2
      stationColors[i] = interpolate(i, 6, STATION_COLORS_LENGTH / 2, gradientColor1, gradientColor2);
    } else {
      // now gradient back going from gradientColor2 back to gradientColor1
      stationColors[i] = interpolate(i, (STATION_COLORS_LENGTH / 2) + 1, STATION_COLORS_LENGTH - 5, gradientColor2, gradientColor1);
    }
  }
  strip.begin();  // Initialize pins for output
  updatePixels();
}
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

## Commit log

2018-09-19 added working test code for Si4703 chip on LinkSprite board, for use with Arduino
2018-09-19 documented startup more clearly, added scrolling text, which seems to introduce a huge delay, added some Arduino Microbit libraries
2018-09-19 get Microbit buttons working and added notes for it
2018-09-20 added LED test code
2018-09-24 LEDs driven off of Microbit, LEDs updating with current station, Current station changing with Microbit A and B buttons
2018-09-26 switched from soft SPI on Microbit to Hardware SPI, now working with 3V level shifter
2018-09-26 added Fritizing diagram of current breadboard
    [final_breadboard.fzz]
2018-09-26 added current breadboard export to github
2018-10-03 track average speed over time of two photogates
2018-10-08 updated LED offsets and spacing, now using 3m of LEDs, updating LEDs for all stations
2018-10-09 added additional tabs, organization, changed code for updated plexi wheel
2018-10-17 update pixels at fixed 60fps rate
    [fmradio.ino, leds.ino, photogate.ino]
2018-10-17 now tuning from 86.5—107.9
2018-10-17 direction now working on channel wheel, maybe volume too, hard to tell
2018-10-17 maybe fixed station offsets?
    [leds.ino]
2018-10-26 datalogging tests with Arduino Uno
2018-10-26 adafruit datalogging board tests now working with BBC microbit :)
2018-11-02 Added volume at beginning of LED strip
2018-11-02 wheel direction and avocado now correctly determining volume
    [photogate.ino]
2018-11-02 LEDs updates
2018-11-07 cleaned up printing of serial debug, implemented clearer method of photogate encoder, only updating channel/volume on change detected
2018-11-07 renamed arduino sketch to PublicRadio
2018-11-07 FIX: wheels now very responsive, measuring photogates with interrupt handlers
    [PublicRadio.ino]
2018-11-07 separate interrupts for each sensor, limit how often we perform radio updates
2018-11-07 fix two extra bulbs at end of station track
    [PublicRadio.ino]
2018-11-07 do not show wraparound white leds for first and last channel station
2018-11-07 switch to unsigned long for all durations to fix 49.7 days millis rollover
    [fmradio.ino, leds.ino, photogate.ino]
2018-11-12 FIX: ticks now correspond correctly to actual FM stations :)
    [Si4703_Breakout.cpp, fmradio.ino]
2018-11-14 pulses working correctly, but not very pretty yet
    [PublicRadio.ino, fmradio.ino, leds.ino]
2018-11-14 more fast led tests
2018-11-14 reset current tick to white when moving
    [leds.ino]
2018-11-29 now parameterized colors for gradient, updated some timmings to micros instead of millis in LEDs
2018-11-29 change float to int in LEDs
2018-11-29 breath around current channel finger, not on actual finger
2018-11-29 added separate gamma tables for gamma correction, updated gradient a bit
    [GenerateRedGammaTable.pde, PublicRadio.ino, fmradio.ino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]
2018-11-29 moved color specs to top of LED page
2018-11-29 Delete PUBLIC - BOM Public Radio - on gitHub - BOM.csv
    bad format
    [PUBLIC - BOM Public Radio - on gitHub - BOM.csv]
2018-11-29 Add files via upload
    Better Format
    [BOM_Public_Radio.csv]
2018-11-29 Delete BOM_Public_Radio.csv
    bad format again
    [BOM_Public_Radio.csv]
2019-05-10 added more si4703 standalone arduino sketches, added velleman fm tuner board docs
